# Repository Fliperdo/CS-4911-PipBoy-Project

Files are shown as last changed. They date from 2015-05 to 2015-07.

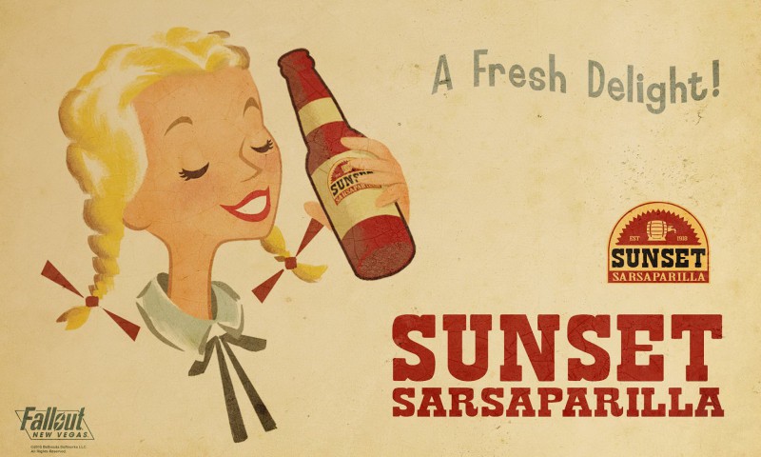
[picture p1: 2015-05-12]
Production_Menu_System/IMAGES/STILLS/NON_IMPLEMENTED_SCREEN.jpg

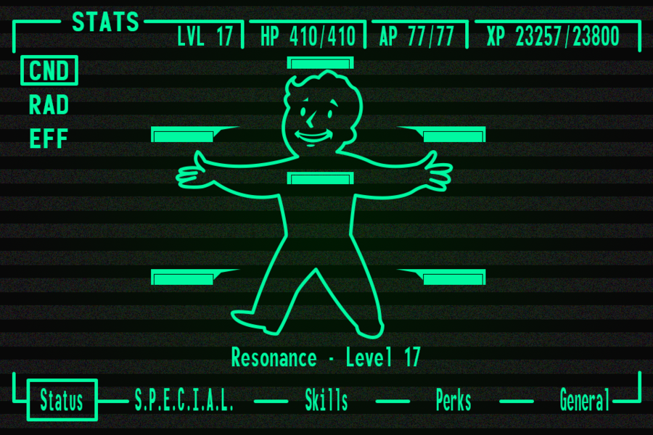
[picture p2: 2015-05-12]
Production_Menu_System/IMAGES/STILLS/Stats_Status.png

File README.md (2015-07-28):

#CS-4911-PipBoy-Project - v0.3
Pip-Boy 4000 in real life.  
This project seeks to implement a student rendition of a Pip-Boy 4000, a newer and more advanced Pip-Boy than the 3000 model. The project consists of hardware and software elements that are wide in scope and are meant for a computer science senior design project. While we feel the project is not hard to reduplicate, we may just not realize how much we have learned. Regardless, basic functionality can be accomplished with a touchscreen and a Raspberry PI 2.

##3D-Print
The 3d print is a redesign based on the model of Yvo de Haas at http://ytec3d.com/pip-boy/ . 
Our version was redesigned to house very specific hardware, mainly adjustments to accommodate a larger 5 inch screen, raspberry pi, and portable usb power supply. Once the parts are printed, they fit together and can be assembled like a large lego set. To make the product permanent, an adhesive such as hot glue can be used to fix the parts together, while small screws are recommended for mounting the electronics.

##Hardware:
Most hardware was chosen for its widespread off-the-shelf availability, relative low cost, and available parts we had lying around. Here is the exact list:  
[Anker Ultra Compact 10000mAh Portable External   Battery](http://www.amazon.com/Anker-10000mAh-Portable-External-Technology/dp/B009USAJCC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)  
[SparkFun FM Tuner Evaluation Board - Si4703](https://www.sparkfun.com/products/10663)  
[2x Thin Speaker](https://www.sparkfun.com/products/10722)  
[NeoPixel Ring - 16 x WS2812 5050 RGB LED](https://www.sparkfun.com/products/12664)  
[Edimax EW-7811Un](http://www.amazon.com/Edimax-EW-7811Un-150Mbps-Raspberry-Supports/dp/B003MTTJOY)  
[ADXL335 - 5V ready triple-axis accelerometer](https://www.adafruit.com/products/163)  
[Raspberry PI 2 Model B](https://www.raspberrypi.org/products/raspberry-pi-2-model-b/)  
[PI Camera Module](https://www.raspberrypi.org/products/camera-module/)  
[Arduino Nano](https://www.arduino.cc/en/Main/ArduinoBoardNano)  
[Logic Level Converter - Bi-Directional](https://www.sparkfun.com/products/12009)  
[HDMI 5" 800x480 Display Backpack - With Touchscreen](http://www.adafruit.com/product/2260)  
The hardware will need self-prepared, low-profile usb and hdmi connectors, as well as 3.5mm jacks. Detailed guides exist on splicing the necessary cables:  
[USB example](https://www.raspberrypi.org/forums/viewtopic.php?f=40&t=32336)  
[3.5mm jack/general wiring exmaple](http://www.hometheatershack.com/forums/remotes-cables-accessories-tweaks/13000-how-solder-illustrated-diy-guide-making-your-own-cables.html)  
Protoboards are recommended. A detailed wiring diagram can be found in the Production_Menu_System/ARDUINO/ directory.

##Software:
The software consists of two parts. The first is a Processing sketch found in `Production_Menu_System/Pip-Boy_4000/Driver` which is a fallout inspired GUI with a multi-tab structure based on the games. The second is the Arduino code found in the `Production_Menu_System/ARDUINO/` directory which handles all hardware interaction. 

##OS:
The environment of the PI is a linux based environment, and so several additional steps for the project to work must be taken. The default bundled java in a plain Processing distributable is not compiled for an ARM device like the PI, so the bundled java needs to be substituted with an ARM-compatible java. To ensure correct functioning of the PIP-Boy 4000 system from bootup, the `/etc/rc.local` script needs the processing command-line invocation to be added to it. Support for Raspberry PI devices also needs to be configured. The camera module can be set up using the `raspi-config` script provided as part of the Raspbian OS. The wifi dongle should be configured like it would on any other linux system. To correct screen orientation, an xorg.conf file must be creted using 
`sudo X -configure`, then the `Option "Rotate" "inverted"` option should be added to the Monitor section of xorg.conf

##License
The included software and data are released under the Beerware license.

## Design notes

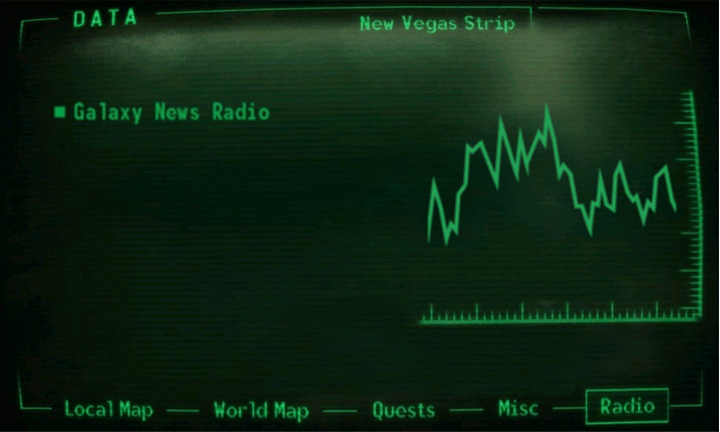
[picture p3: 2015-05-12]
Production_Menu_System/IMAGES/GIFS/RadioScreenGIF.gif

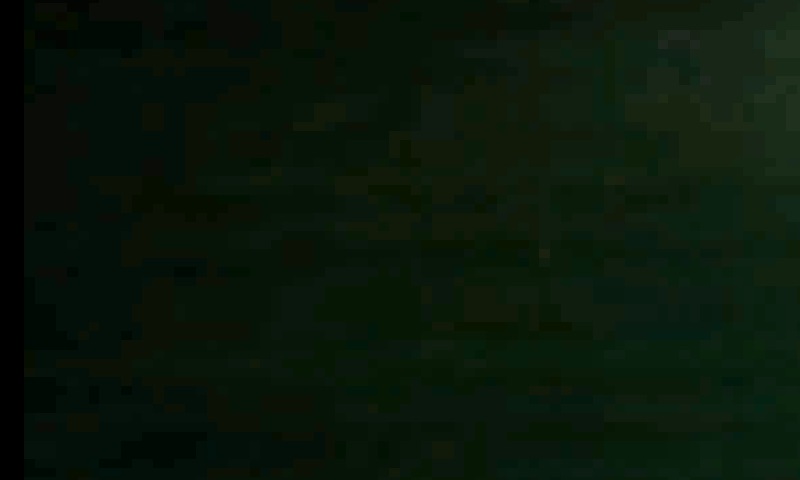
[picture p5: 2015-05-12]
Production_Menu_System/IMAGES/STILLS/RadioScreenGIFBackground.jpg

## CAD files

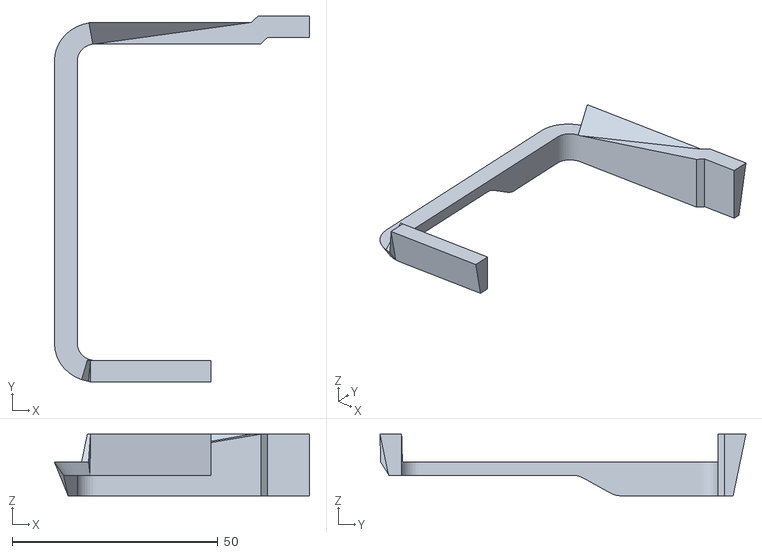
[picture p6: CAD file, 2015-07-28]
Production_Menu_System/3D_MODELS/faceplate0.stl
62.0 x 88.9 x 15.0

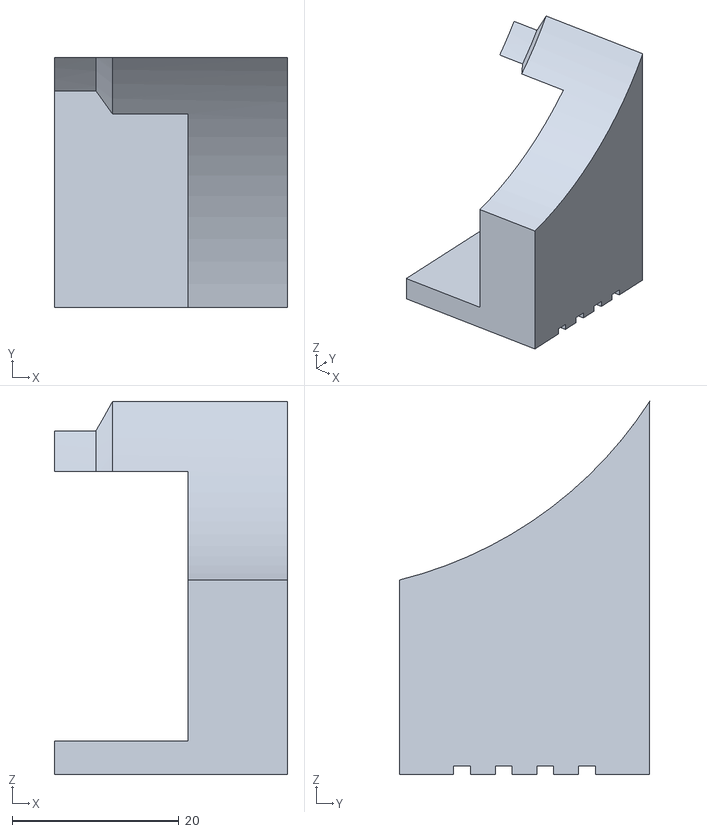
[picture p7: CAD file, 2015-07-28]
Production_Menu_System/3D_MODELS/cover0.stl
28.0 x 30.0 x 44.7

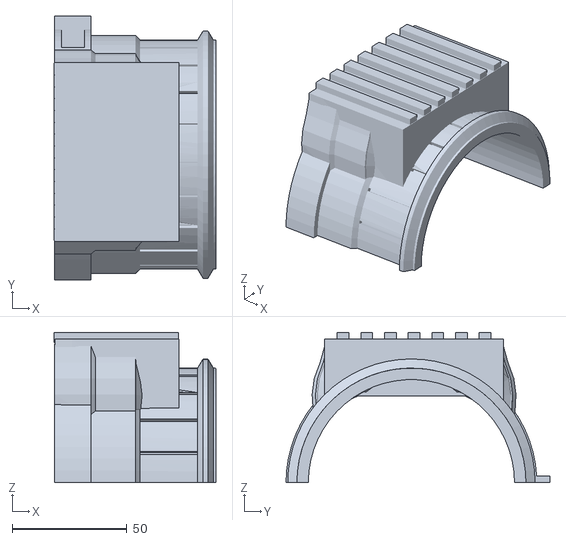
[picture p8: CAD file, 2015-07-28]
Production_Menu_System/3D_MODELS/bottom2.stl
70.5 x 115.3 x 65.6

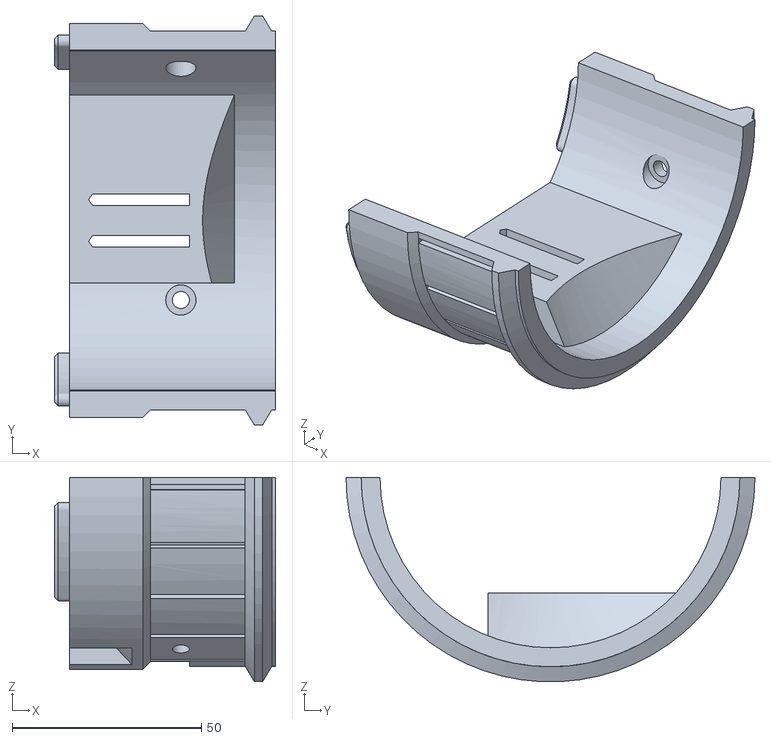
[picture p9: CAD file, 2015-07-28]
Production_Menu_System/3D_MODELS/top2.stl
58.4 x 108.0 x 53.9

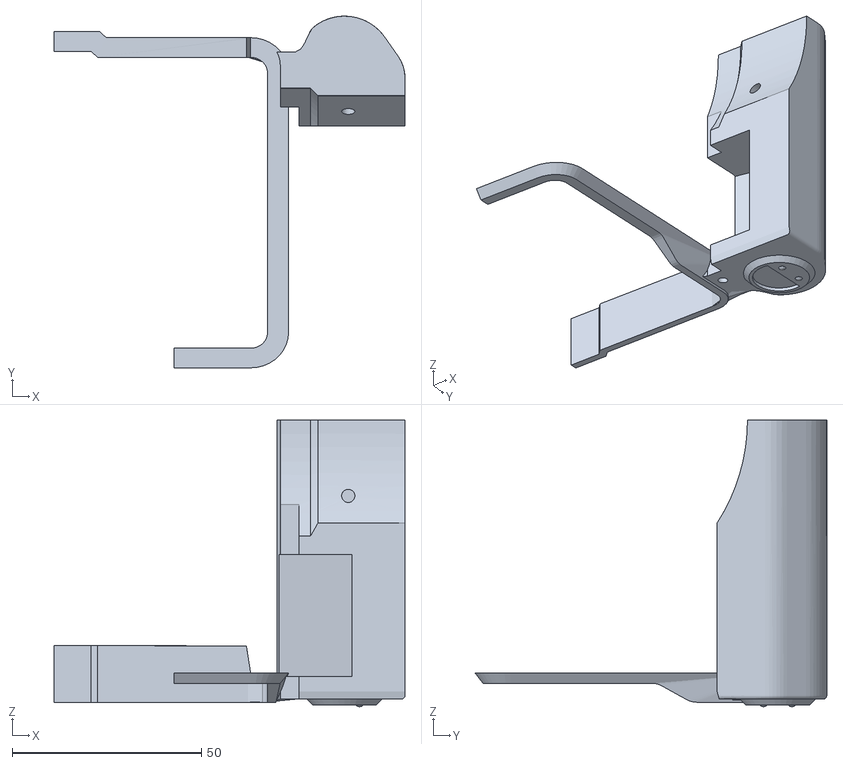
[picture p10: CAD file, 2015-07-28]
Production_Menu_System/3D_MODELS/faceplate1.stl
92.8 x 93.0 x 75.7

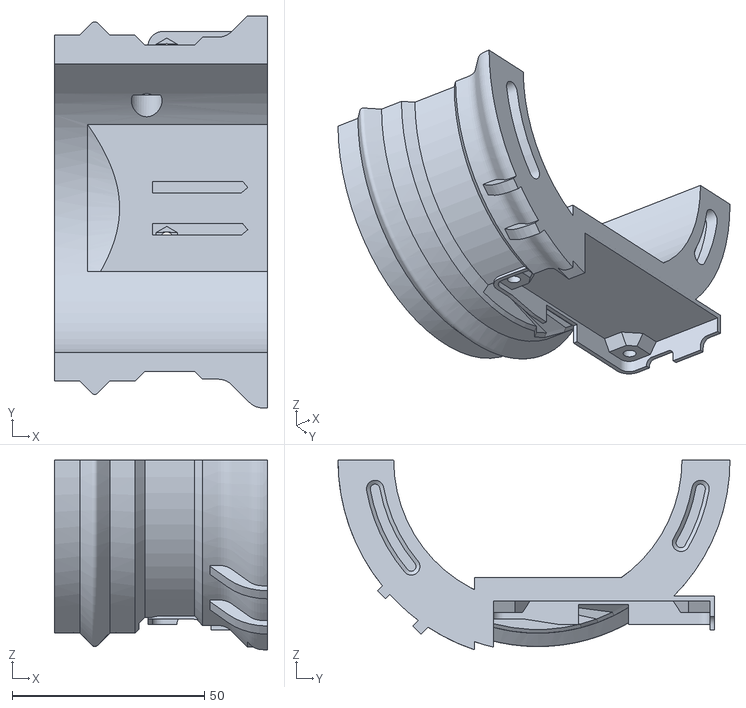
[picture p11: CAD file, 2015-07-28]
Production_Menu_System/3D_MODELS/top0.stl
55.5 x 102.0 x 49.3

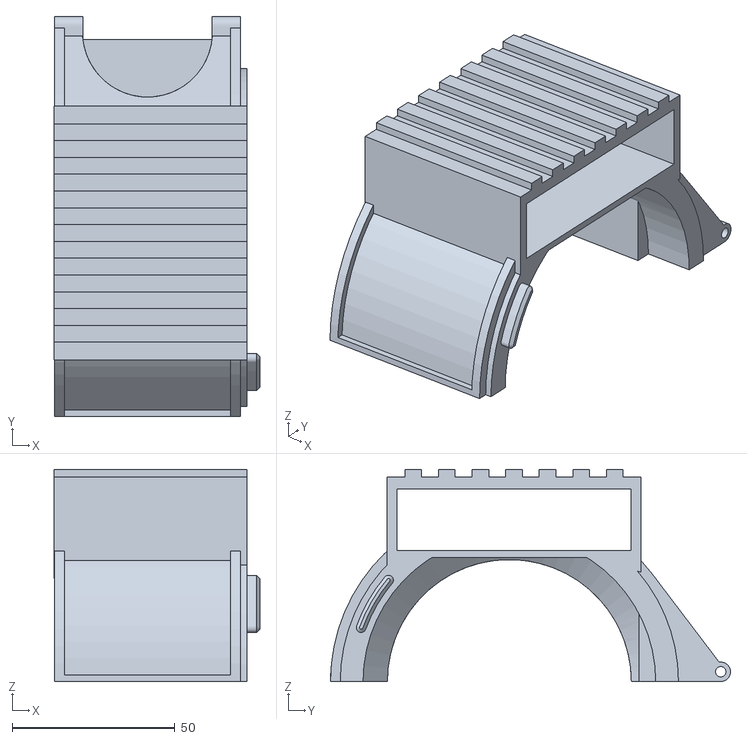
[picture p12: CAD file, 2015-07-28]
Production_Menu_System/3D_MODELS/bottom1.stl
63.3 x 123.0 x 65.2

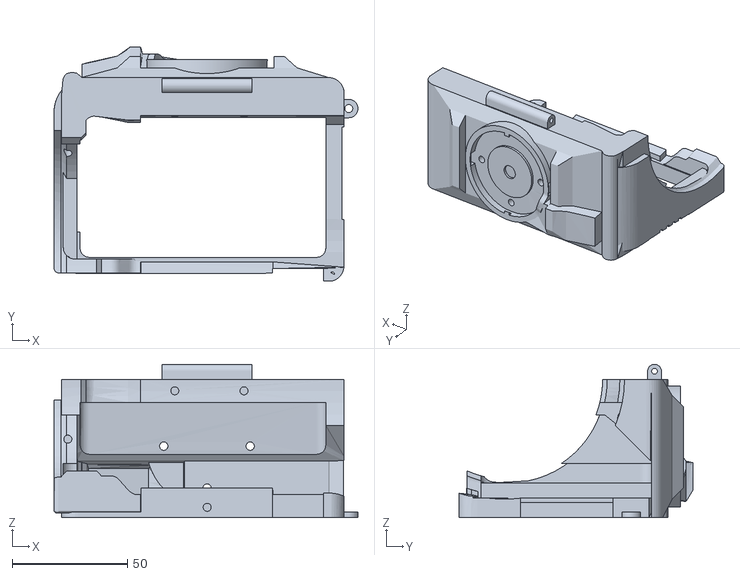
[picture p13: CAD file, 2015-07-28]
Production_Menu_System/3D_MODELS/case.stl
131.8 x 101.6 x 66.5

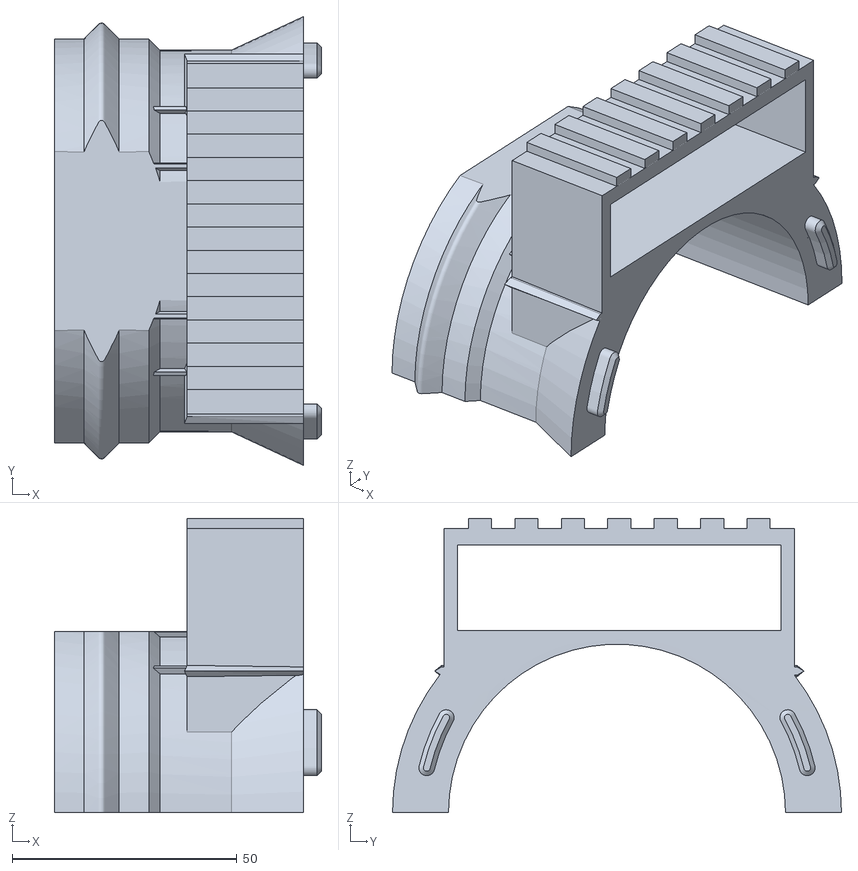
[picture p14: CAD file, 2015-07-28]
Production_Menu_System/3D_MODELS/bottom0.stl
59.5 x 99.9 x 65.5

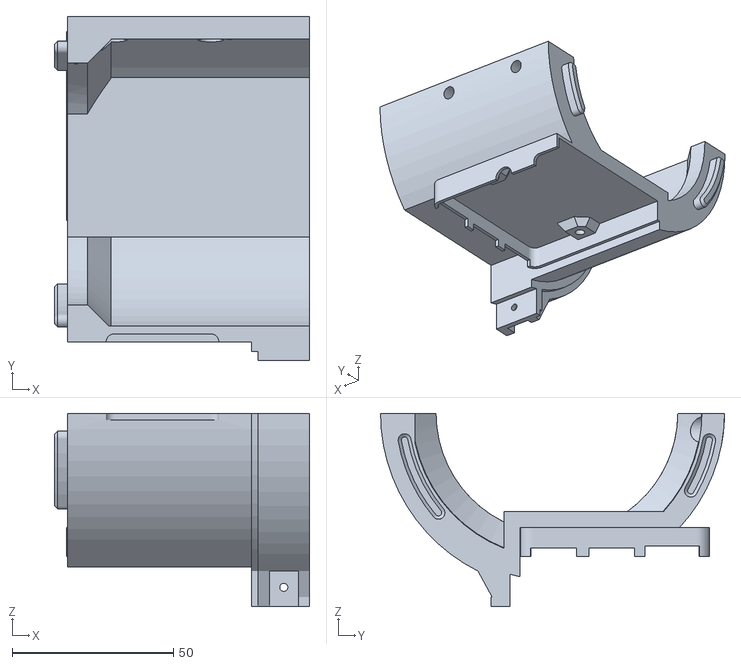
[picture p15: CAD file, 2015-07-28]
Production_Menu_System/3D_MODELS/top1.stl
79.2 x 106.8 x 60.0

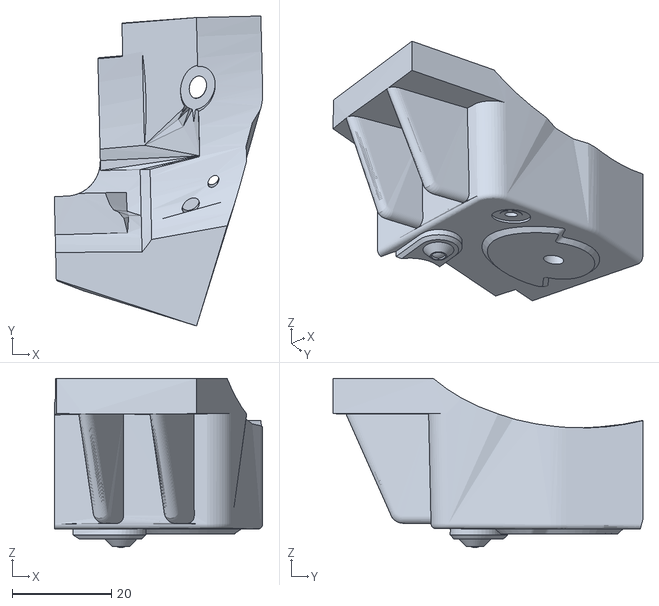
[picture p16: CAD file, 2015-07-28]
Production_Menu_System/3D_MODELS/cover1.stl
41.9 x 62.3 x 34.0

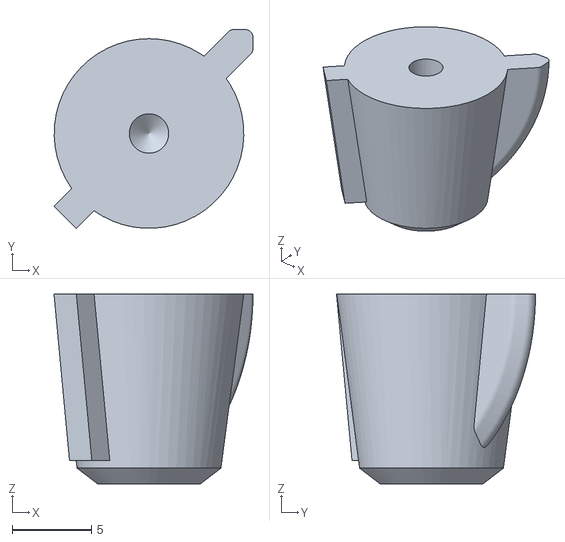
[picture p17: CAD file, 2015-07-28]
Production_Menu_System/3D_MODELS/knob.stl
12.6 x 12.6 x 12.0

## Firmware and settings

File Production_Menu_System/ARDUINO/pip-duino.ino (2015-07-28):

// NeoPixel Ring simple sketch (c) 2013 Shae Erisson
// released under the GPLv3 license to match the rest of the AdaFruit NeoPixel library

#include <Adafruit_NeoPixel.h>
#include <avr/power.h>
#include <SparkFunSi4703.h>
#include <Wire.h>

//radio pin consts
int resetPin = 3;
int SDIO = A4;
int SCLK = A5;

Si4703_Breakout radio(resetPin, SDIO, SCLK);
int channel;
int volume;
char rdsBuffer[10];

//flashlight consts
unsigned char MAX_RGB=100;
struct RGB{
  unsigned char r,g,b;
} r_col;
int party_it=0;

bool light_on = true;
bool ismute = true;
bool isparty = false;

// Neopixel output pin
#define PIN            2

// number of connected neopixels
#define NUMPIXELS      16

Adafruit_NeoPixel pixels = Adafruit_NeoPixel(NUMPIXELS, PIN, NEO_GRB + NEO_KHZ800);

int delayval = 500; // delay for half a second

// Input a value 0 to 255 to get a color value.
// The colours are a transition r - g - b - r.
uint32_t Wheel(byte WheelPos) {
  WheelPos = 255 - WheelPos;
  if(WheelPos < 85) {
   return pixels.Color(255 - WheelPos * 3, 0, WheelPos * 3);
  } else if(WheelPos < 170) {
    WheelPos -= 85;
   return pixels.Color(0, WheelPos * 3, 255 - WheelPos * 3);
  } else {
   WheelPos -= 170;
   return pixels.Color(WheelPos * 3, 255 - WheelPos * 3, 0);
  }
}

void setup() {
  pixels.begin(); // This initializes the NeoPixel library.
    Serial.begin(9600);
  Serial.println("\n\nSi4703_Breakout Test Sketch");
  Serial.println("===========================");  
  Serial.println("a b     Favourite stations");
  Serial.println("+ -     Volume (max 15)");
  Serial.println("u d     Seek up / down");
  Serial.println("r       Listen for RDS Data (15 sec timeout)");
  Serial.println("Send me a command letter.");
  
  for(int i=0;i<NUMPIXELS;i++){
    pixels.setPixelColor(i, pixels.Color(0,50,0)); // Moderately bright green color.
    pixels.show(); // This sends the updated pixel color to the hardware.
  }

  radio.powerOn();
  radio.setVolume(15);
}

void loop() {

  /*
  * Arduino Output
  */
  
   //process accelerometer data and send step message to pi
   if(analogRead(A0)>500){
       Serial.println("STP"); 
   }
   //report radio station to pi
   Serial.print("CHN");
   Serial.println(channel);
   
   Serial.flush();


 /*
  * Arduino Input
  */

  //char *serbuf = (char*)malloc(10*sizeof(char));
  char serbuf[10];
   if (Serial.available()){
    Serial.readBytesUntil('\n', serbuf, 10);
//read rgb values from pi
    if (strncmp(serbuf, "RGB", 3) == 0 ){
      Serial.println("reaceived RGB");
      for(int i=0;i<NUMPIXELS;i++){
        r_col.r = (unsigned char) map(serbuf[3], 0, 255, 0, MAX_RGB);
        r_col.g = (unsigned char) map(serbuf[4], 0, 255, 0, MAX_RGB);
        r_col.b = (unsigned char) map(serbuf[5], 0, 255, 0, MAX_RGB);
        
        if(light_on){
          pixels.setPixelColor(i, pixels.Color(r_col.r, r_col.g, r_col.b)); 
        }else{
          pixels.setPixelColor(i, pixels.Color(0,0,0)); 
        }
      }
      pixels.show();
    } 
//read channel seek direction from pi
    else if(strncmp(serbuf, "CHS", 3) == 0){
      Serial.println("reaceived CHS");
      if(serbuf[3] == '+'){
        channel = radio.seekUp();
        displayInfo();
      }else if(serbuf[3] == '-'){
        channel = radio.seekDown();
        displayInfo();
      }
//read volume delta from pi
    }else if(strncmp(serbuf, "VOL", 3) == 0){
      Serial.println("reaceived VOL");
      if(serbuf[3] == '+'){
        volume ++;
        if (volume == 16) volume = 15;
      }else if(serbuf[3] == '-'){
        volume --;
        if (volume < 0) volume = 0;
      }
      if(ismute)
        radio.setVolume(0);
      else
        radio.setVolume(volume);
//read light on from pi
    }else if(strncmp(serbuf, "LON", 3) == 0){
      Serial.println("reaceived LON");
      light_on = true;
//read light off from pi
    }else if(strncmp(serbuf, "LOF", 3) == 0){
      Serial.println("reaceived LOF");
      light_on = false;
//read radio mute from pi
    }else if(strncmp(serbuf, "MUT", 3) == 0){
      Serial.println("reaceived MUT");
      ismute = !ismute;
//read party mode light pattern from pi
    }else if(strncmp(serbuf, "PMD", 3) == 0){
      Serial.println("reaceived PMD");
      isparty = !isparty;
//read brightness value from pi
    }else if(strncmp(serbuf, "BRT", 3) == 0){
      Serial.println("reaceived BRT");
      /*
      r_col.r = (unsigned char) map(r_col.r, 0, curr_brightness, 0, strcmp[3]);  
      r_col.g = (unsigned char) map(r_col.g, 0, MAX_RGB, 0, strcmp[3]);
      r_col.b = (unsigned char) map(r_col.b, 0, MAX_RGB, 0, strcmp[3]); 
      */
    }else if(strncmp(serbuf, "AFM", 3) == 0){
      Serial.println("reaceived AFM");
//no known am/fm command in radio module    
    }
    /*
    else if (ch == 'a')
    {
      channel = 930; // Rock FM
      radio.setChannel(channel);
      displayInfo();
    }
    else if (ch == 'r')
    {
      Serial.println("RDS listening");
      radio.readRDS(rdsBuffer, 15000);
      Serial.print("RDS heard:");
      Serial.println(rdsBuffer);      
    }
    */
  }
//update flashlight
  if(isparty){
    for(int i=0; i<pixels.numPixels(); i++) {
      pixels.setPixelColor(i, Wheel(((i * 256 / pixels.numPixels()) + party_it) & 255));
    }
    pixels.show();
    party_it = (party_it > 256*5)? 0 : ++party_it;
  }
}

void displayInfo()
{
   Serial.print("Channel:"); Serial.print(channel); 
   Serial.print(" Volume:"); Serial.println(volume); 
}

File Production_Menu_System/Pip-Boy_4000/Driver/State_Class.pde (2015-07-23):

class State {
  String hello;
  //Menu Item State
  int currentPageIndex = 0;
  int currentCategoryIndex = 0;
  boolean piConnected = false;
  int stepCount = 0;
  boolean step = false;
  boolean oldsStep = false;
  int caloriesBurnt = 0;
  int caloriesBurntFromStepsOld = 0;
  int caloriesBurntFromSteps = 0;
  boolean clickNoticed = true;
  Point click;
  String currentChannel = "";
  boolean changeAMorFM = false;
  boolean channelUp = false;
  boolean channelDown = false;
  boolean nextSong = false;
  boolean prevSong = false;
  boolean playingMusic = false;
  Minim minim;
  PImage cameraImage;
  boolean lightChanged = false;
  boolean isLightOn = false;
  int lightBrightness = 50;
  boolean changeOfColor = false;
  boolean changeOfBrightness;
  char redLevel = 100;
  char blueLevel = 100;
  char greenLevel = 100;
  int currentSong = 0;
  State() {
    hello = "hello from state.update()";
    assignSongs();
  }
  
  void update(){
    readSerialPort();
    updatePageIndex();
    updateStepCount();
    updateCalories();
    updateRadio();
    updateLight();
    //println(hello);
  }
  
  void readSerialPort() {
    if (myPort != null) {
    int newLine = 10; //ASCII
    String codeDataString = null;
    String myString;
    if (myPort.available() > 0) {
      myString = myPort.readStringUntil(newLine);
      if (myString != null) {
        println(myString);
        if (myString.contains("STP")) {
          stepCount++;
        } else if (myString.contains("CHN")) {
          String temp = myString.substring(3, 7); //definitely 3 -- CHN#
          String a = Character.toString(temp.charAt(0));
          String b = Character.toString(temp.charAt(1));
          String c = Character.toString(temp.charAt(2));
          String d = Character.toString(temp.charAt(3));
          if (temp.charAt(0) == '0')
          {            
            currentChannel = b +  c + "." + d;
          }
          else 
          {
            currentChannel = a + b + c + "." + d;
          }
          println(currentChannel);
        } else {
          println("Possible Read Error");
        }
      }
    }
    }
  }
  
  void updatePageIndex() {
    //can use key/button interupts here if hardware exists
  }
  int LEFT  = 37;
  int RIGHT = 39;
  int UP    = 38;
  int DOWN  = 40;  
  int ENTER = 10;
  int Z = 90;
  int X = 88;
  int C = 67;

  void updatePageIndex(int changeDirection) {
    //playTransitionSounds(changeDirection);
    //transitionScreenNoise();

    if (changeDirection == RIGHT) {
      currentPageIndex = currentPageIndex + 1;
    } else
    if (changeDirection == LEFT) {
      currentPageIndex = currentPageIndex - 1;
    } else 
    if (changeDirection == Z) {
      currentCategoryIndex = 0;
    } else
    if (changeDirection == X) {
      currentCategoryIndex = 1;
    } else
    if (changeDirection == C) {
      currentCategoryIndex = 2;
    } else {
      currentPageIndex = changeDirection;
    }
  }
  
  int getCurrentPageIndex() {
    return currentPageIndex;
  }
    
  int getCurrentCategoryIndex() {
    return currentCategoryIndex;
  }
    
  void setCurrentPageIndex(int a) {
    currentPageIndex = a;
  }
    
  void updateStepCount(){
  }
  
  void updateCalories(){
    caloriesBurntFromSteps = (stepCount / 100) * 5;
    caloriesBurnt = caloriesBurnt + (caloriesBurntFromSteps - caloriesBurntFromStepsOld);
    caloriesBurntFromStepsOld = caloriesBurntFromSteps;
  }
  
  int getStepCount(){
    return stepCount;
  }

  
  int getSteps() {
    return stepCount;
  }
  
  void addCalories(int cals) {
    caloriesBurnt = caloriesBurnt + cals;
  }
  
  void removeCalories(int cals) {
    caloriesBurnt -= cals;
  }
  
  void resetCalories() {
    caloriesBurnt = 0;
  }
  
  int getCalories(){
    return caloriesBurnt;
  }
  
  void registerClick() {
    clickNoticed = true;
  }
  
  void click(int x, int y) {
    click = new Point(x,y);
    clickNoticed = false;
  }
  
  boolean hasClick() {
    return !clickNoticed;
  }
  
  Point getClick() {
    return click;
  }
  
  //May need manager classes for each
  void updateRadio() {
    if (channelUp) {
      println("Send channelUp code to Ard");
      if (myPort != null){myPort.write("CHS+\n");}
      channelUp = false; 
    }
    if (channelDown) {
      println("Send channelDown code to Ard");
      if (myPort != null){myPort.write("CHS-\n");}
      channelDown = false;  
    }
    if (changeAMorFM) {
      println("Send alternateFM_AM code to Ard");
      if (myPort != null){myPort.write("AFM\n");}
      changeAMorFM = false;
    }
  }
  
  void channelUp() {
    channelUp = true;
  }
  
  void channelDown() {
    channelDown = true;
  }
  
  void alternateAMorFM() {
    changeAMorFM = true;
  }
   
  void nextSong() {
    songs[currentSong % songs.length].pause();
    currentSong++;
    songs[currentSong % songs.length].rewind();    
    songs[currentSong % songs.length].play();    
  }
  
  void prevSong() {
    songs[currentSong % songs.length].pause();
    currentSong--;
    if (currentSong < 0) {
      currentSong = songs.length - 1;
    }
    songs[currentSong % songs.length].rewind();    
    songs[currentSong % songs.length].play();    
  }
  
  void playMusic() {
    if (myPort != null){myPort.write("MUT\n");}
    println(currentSong % songs.length);
    songs[currentSong % songs.length].play();    
    playingMusic = true;
  }
  
  void pauseMusic() {
    if (myPort != null){myPort.write("MUT\n");}
    songs[currentSong % songs.length].pause();
    playingMusic = false;
  }
  
  boolean isPlayingMusic() {
    return playingMusic;
  }
  
  Minim getMinim() {
    return minim;
  }
  
  void assignSongs() {
  }
  
  void updateCameraImage() {
    println("Image from camera get");
  }
  
  PImage getCameraImage() {
    return null;
  }
  
  void updateLight() {
    if (lightChanged) {
      if (isLightOn) {
        if (myPort != null){myPort.write("LOF\n");}
      } else {
        if (!isLightOn) {
        if (myPort != null){myPort.write("LON\n");}
        }
        lightChanged = false;
      }
    }
    if (changeOfBrightness) {
      if (myPort != null){myPort.write("BRT" + char(lightBrightness) + "\n");}
      changeOfBrightness = false;
    }
    if (changeOfColor) {
      if (myPort != null) {myPort.write("RGB" + redLevel + greenLevel + blueLevel + "\n"); }//http://www.tutorialspoint.com/java/java_string_getbytes.htm
      changeOfColor = false;
    }
    //if light has changed on off send code
    //if RGB changed send RGB code change
    //if birghtness changed send RGB code change
  }
  
  void lightOn() {
    isLightOn = true;
    lightChanged = true;
  }
  
  void lightOff() {
    isLightOn = false;
    lightChanged = true;
  }
  
  void lightBrightness(int change) {
    lightBrightness = lightBrightness + change;
    if (lightBrightness > 100) {
      lightBrightness = 100;
    }
    if (lightBrightness < 0) {
      lightBrightness = 0;
    }
    changeOfBrightness = true;
  }
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

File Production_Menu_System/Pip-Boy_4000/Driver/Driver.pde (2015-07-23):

import java.lang.management.*;
import ddf.minim.*;
import gifAnimation.*;
import processing.serial.*;
import java.util.Calendar;
import java.util.GregorianCalendar;
import java.text.SimpleDateFormat;
Serial myPort;
Minim minim;
AudioPlayer firstSong;
String song1Name = "Bingo Bango Bongo.mp3";
AudioPlayer secondSong;
String song2Name = "World On Fire.mp3";
AudioPlayer[] songs;
String[] songNames;

MainDriver PipBoyMenu;

void setup() 
{
    size(800,480);
    minim = new Minim(this);
    //need to handle case of no serial port
    //myPort = new Serial(this, Serial.list()[0], 9600);
    //println(Serial.list()[0]);
    PipBoyMenu = new MainDriver();
    firstSong = minim.loadFile(song1Name);
    secondSong = minim.loadFile(song2Name);
    songs = new AudioPlayer[] {firstSong, secondSong};
    songNames = new String[] {song1Name, song2Name};
}
void draw() 
{
  PipBoyMenu.drive();
}
class MainDriver {
  UI mainUI;
  Input mainInput;
  Output mainOutput;
  State mainState;
  
  MainDriver() {
    mainState = new State();
    mainUI = new UI(mainState);
    mainInput = new Input();
    mainOutput = new Output();
  }
  
  void drive() {
    mainInput.read();
    mainState.update();
    mainUI.display();
    mainOutput.write(); 
  }
  
  State getState(){
    return mainState;
  }
  
}

void keyPressed () {
  println(keyCode);
  PipBoyMenu.getState().updatePageIndex(keyCode);
}

void mousePressed() {
  PipBoyMenu.getState().click(mouseX, mouseY);
}

boolean sketchFullScreen() {
  return false;
}

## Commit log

2015-05-12 Upload Of Work To Date On The Pip Boy
    This is everything software related that my group member, Jacob Binder
    and I completed in our Prototyping Intelligent Appliances course.
    [Pip boy 3000 Back part 1.STL, Pip boy 3000 Back part 2.STL, Pip boy 3000 Back part 3.STL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]
2015-06-15 Remove Alternate Project Versions to Clean
    Basically clean slate for the new model.
    [Pip boy 3000 Back part 1.STL, Pip boy 3000 Back part 2.STL, Pip boy 3000 Back part 3.STL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]
2015-07-10 Added Serial Port Functionality and Updated Visual Aspects Significantly.
    The serial commands have be littered throughout where printlns once were
    and I have added a number of art assets to the UI and continue to do so.
    This current build will only run with USB plugged in. Otherwise it wont
    start the program.
2015-07-14 Added Funtional On Screen Navigation Buttons
    This is a crude addition of the navigation buttons to the UI that adds
    the menu categories to the bottom and borderless sub category changing
    buttons to the sides.
2015-07-28 added hardware side code and 3d models
    [bottom0.stl, bottom1.stl, bottom2.stl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]
